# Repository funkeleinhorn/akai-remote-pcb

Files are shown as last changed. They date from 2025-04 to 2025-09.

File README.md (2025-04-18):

# Keymatrix




A PCB which fits in the remote control port of AKAI GX 635s featuring an ESP32 to allow remote control.
This project is licensed as open hardware. See LICENSE.txt for details.

## Images

Here you can see how the PCB looks:

top
bottom

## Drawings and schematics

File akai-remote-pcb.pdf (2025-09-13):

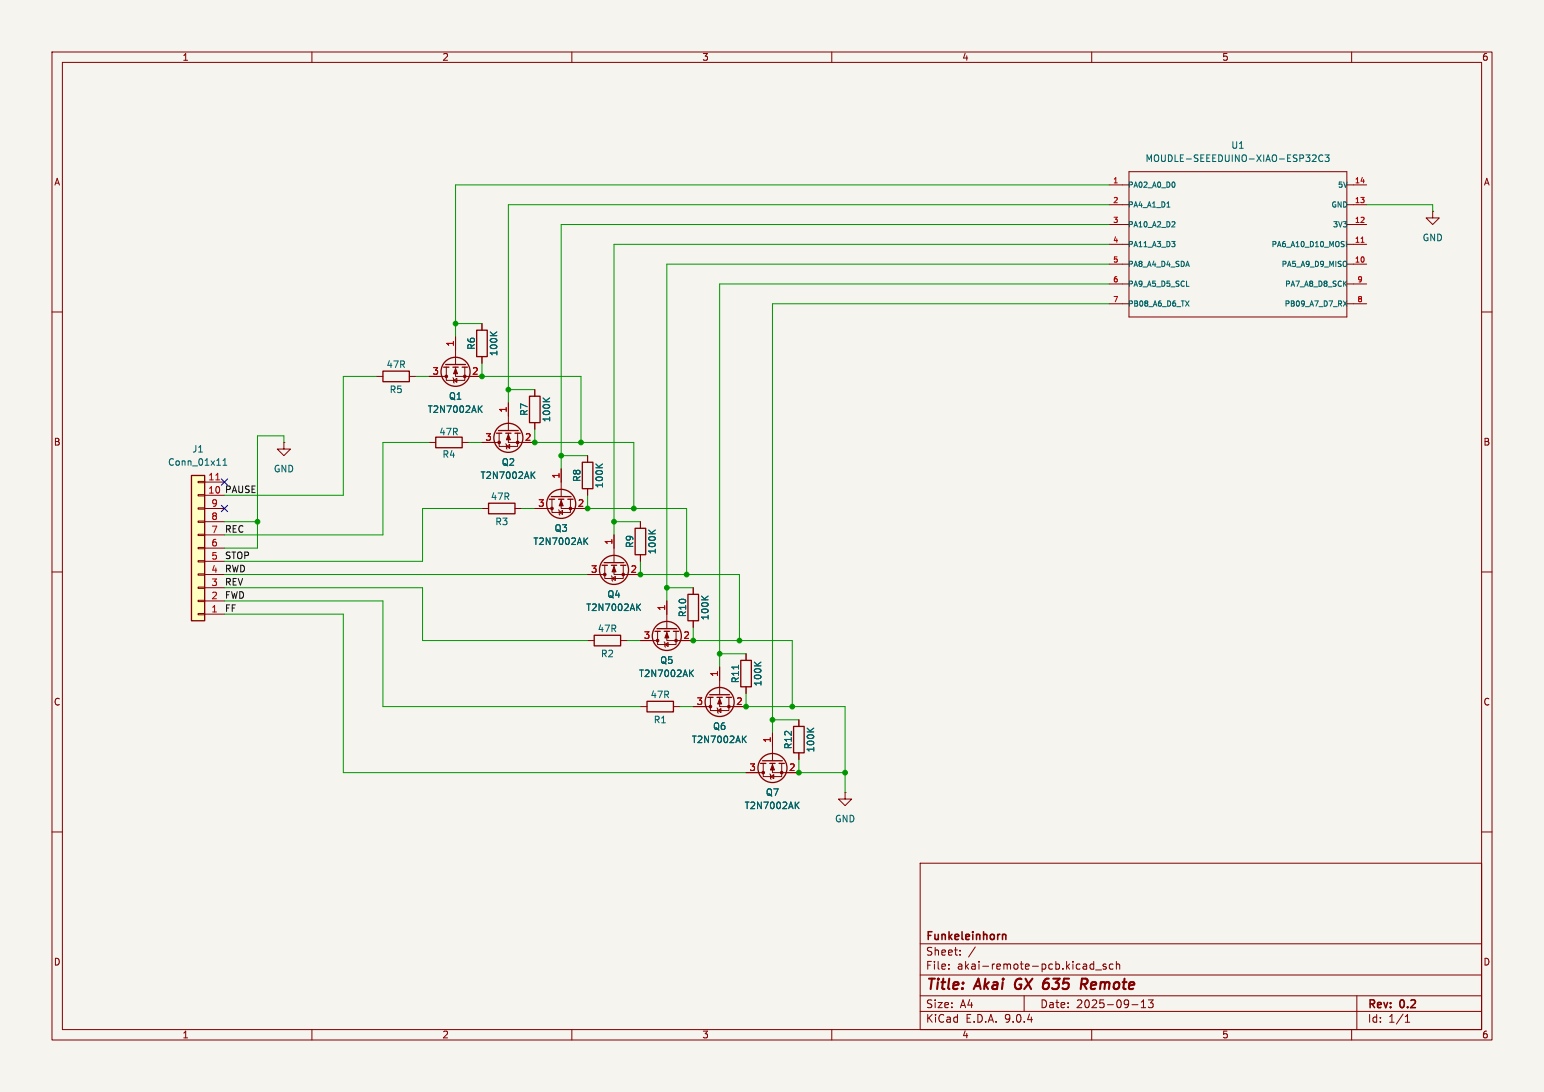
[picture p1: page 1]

Id: 1/1 Title: Akai GX 635 Remote

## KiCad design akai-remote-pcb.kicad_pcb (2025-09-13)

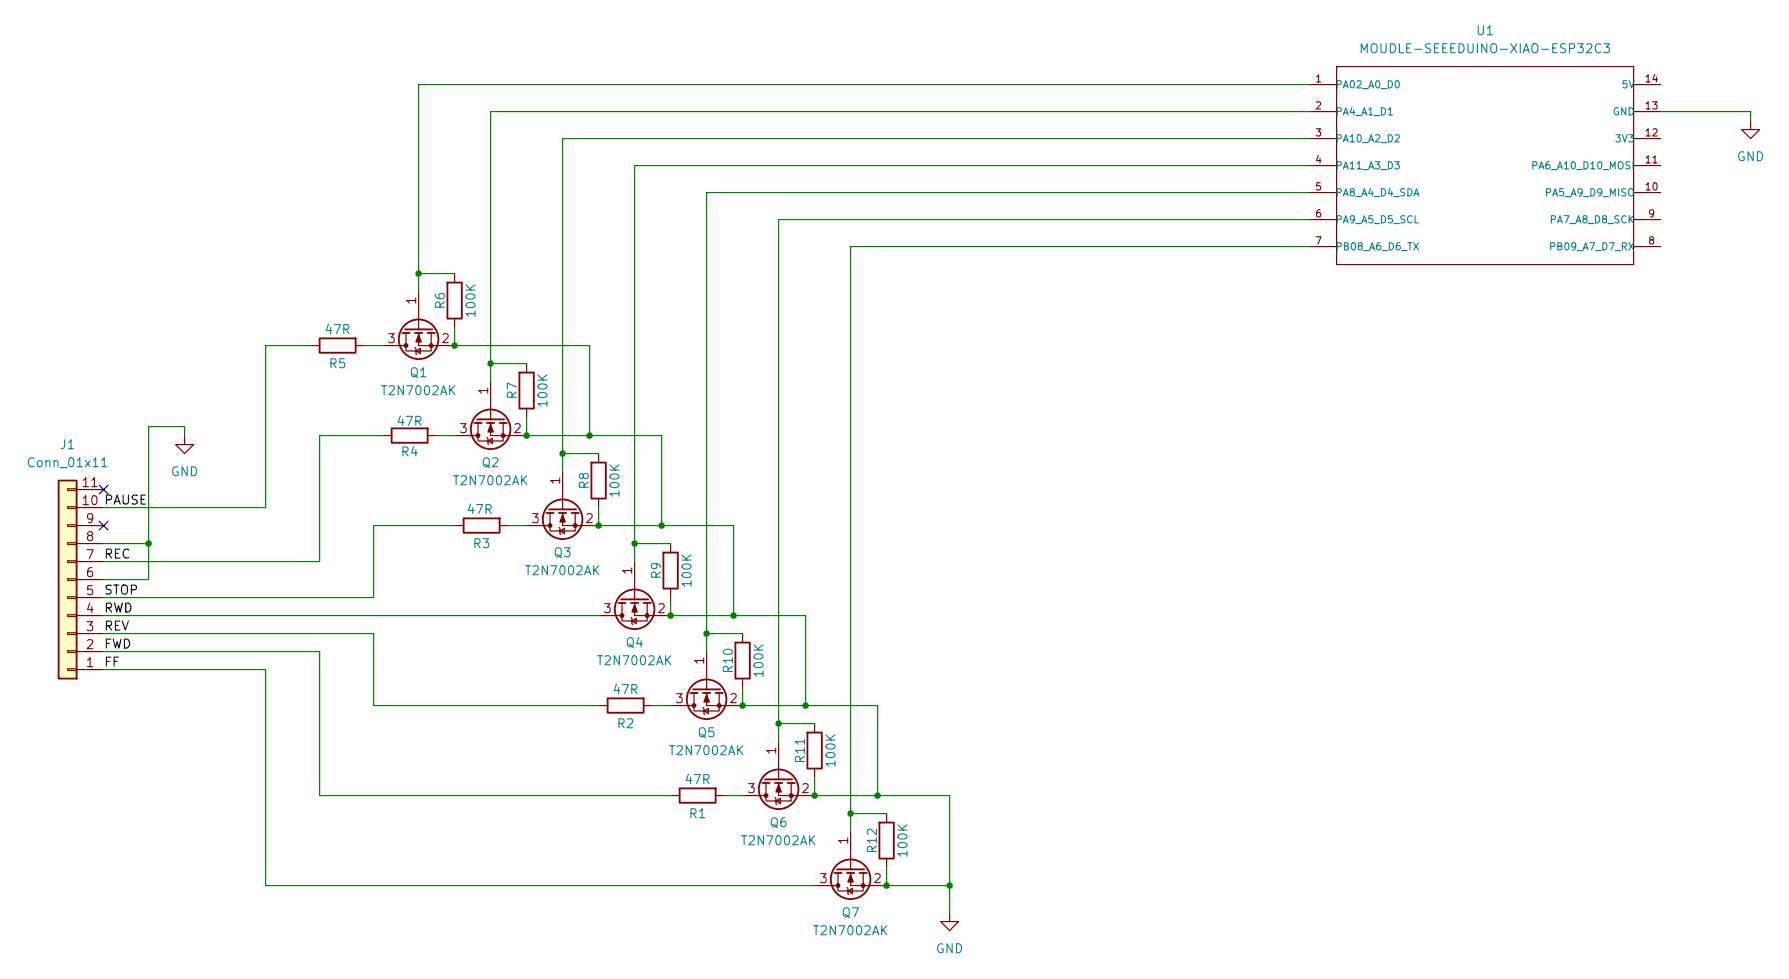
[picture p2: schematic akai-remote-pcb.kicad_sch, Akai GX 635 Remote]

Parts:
J1: Conn_01x11; AKAI_GX_635_REMOTE_CONTROL_PORT
Q1, Q2, Q3, Q4, Q5, Q6, Q7: T2N7002AK; SOT-23
R1, R2, R3, R4, R5: 47R; R_0603_1608Metric
R6, R7, R8, R9, R10, R11, R12: 100K; R_0603_1608Metric
U1: MOUDLE-SEEEDUINO-XIAO-ESP32C3; MOUDLE14P-SMD-2.54-21X17.8MM

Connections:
/FF: J1.1, Q7.3 (D)
/FWD: J1.2, R1.1
/PAUSE: J1.10, R5.1
/REC: J1.7, R4.1
/REV: J1.3, R2.1
/RWD: J1.4, Q4.3 (D)
/STOP: J1.5, R3.1
GND: J1.6, J1.8, Q1.2 (S), Q2.2 (S), Q3.2 (S), Q4.2 (S), Q5.2 (S), Q6.2 (S), Q7.2 (S), R6.1, R7.1, R8.1, R9.1, R10.1, R11.1, R12.1, U1.13 (GND)
unnamed: Q1.3 (D), R5.2
unnamed: Q1.1 (G), R6.2, U1.1 (PA02_A0_D0)
unnamed: Q2.3 (D), R4.2
unnamed: Q2.1 (G), R7.2, U1.2 (PA4_A1_D1)
unnamed: Q3.3 (D), R3.2
unnamed: Q3.1 (G), R8.2, U1.3 (PA10_A2_D2)
unnamed: Q4.1 (G), R9.2, U1.4 (PA11_A3_D3)
unnamed: Q5.3 (D), R2.2
unnamed: Q5.1 (G), R10.2, U1.5 (PA8_A4_D4_SDA)
unnamed: Q6.3 (D), R1.2
unnamed: Q6.1 (G), R11.2, U1.6 (PA9_A5_D5_SCL)
unnamed: Q7.1 (G), R12.2, U1.7 (PB08_A6_D6_TX)

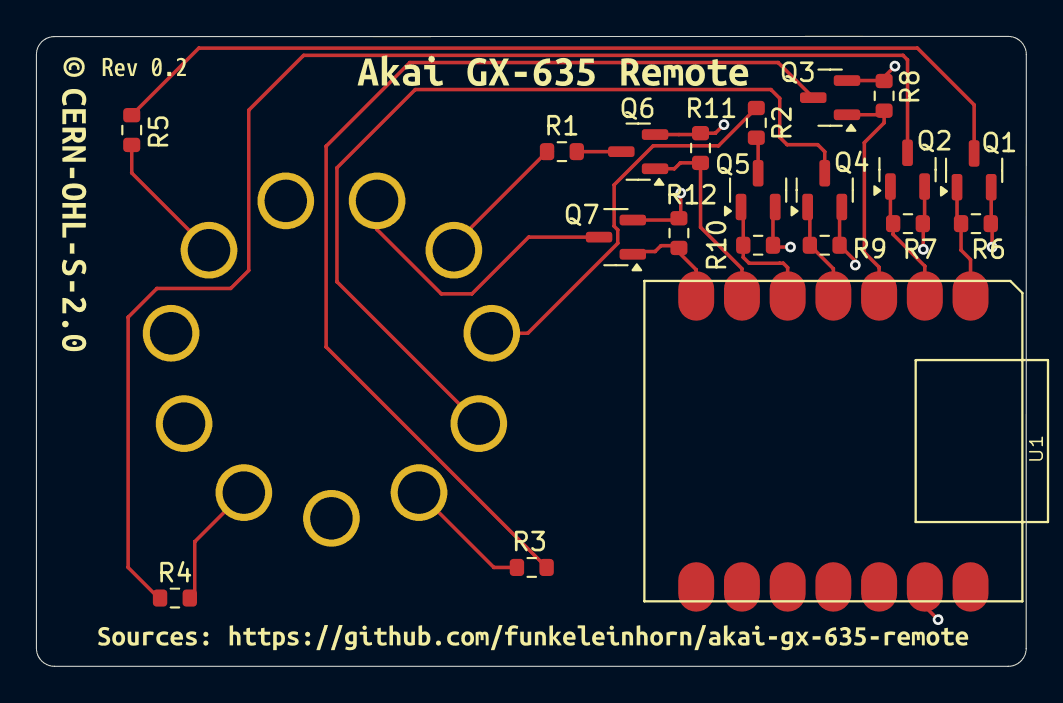
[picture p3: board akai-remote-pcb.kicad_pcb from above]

Board: 2 copper layers, 55.0 x 35.0 mm, 26 parts (0 on the bottom side), 20 nets.

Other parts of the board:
kibuzzard-67B602E2: G***; kibuzzard-67B602E2
kibuzzard-67B602EE: G***; kibuzzard-67B602EE
kibuzzard-67B60253: G***; kibuzzard-67B60253
kibuzzard-67B60319: G***; kibuzzard-67B60319
kibuzzard-68C59956: G***; kibuzzard-68C59956

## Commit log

2025-09-13 Fix MOSFET direction and add external pull-down resistors
    This commit fixes the direction of the MOSFETs and adds external
    pull-down resistors to their gates to prevent undefined behavior when
    the ESP is not powered.
    [akai-remote-pcb.kicad_pcb, akai-remote-pcb.kicad_sch]
2025-09-13 chore: update schematic PDF [skip ci]
